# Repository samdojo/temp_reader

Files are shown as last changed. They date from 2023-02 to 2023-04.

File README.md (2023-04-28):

# Tempurature reader

This repo contains the schematic, code, and 3D print file to build a simple temperature reader

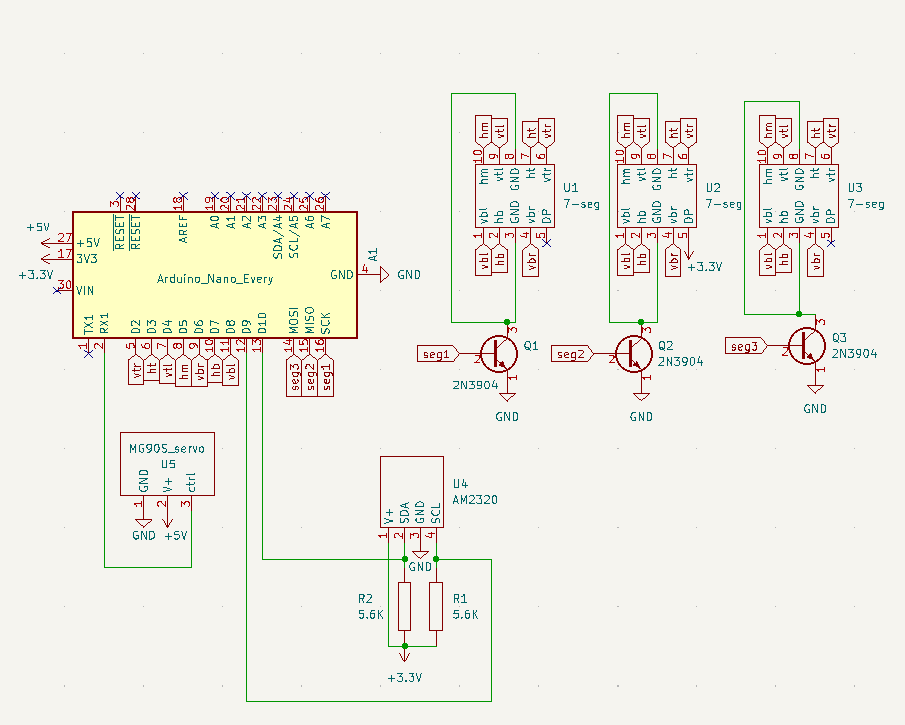
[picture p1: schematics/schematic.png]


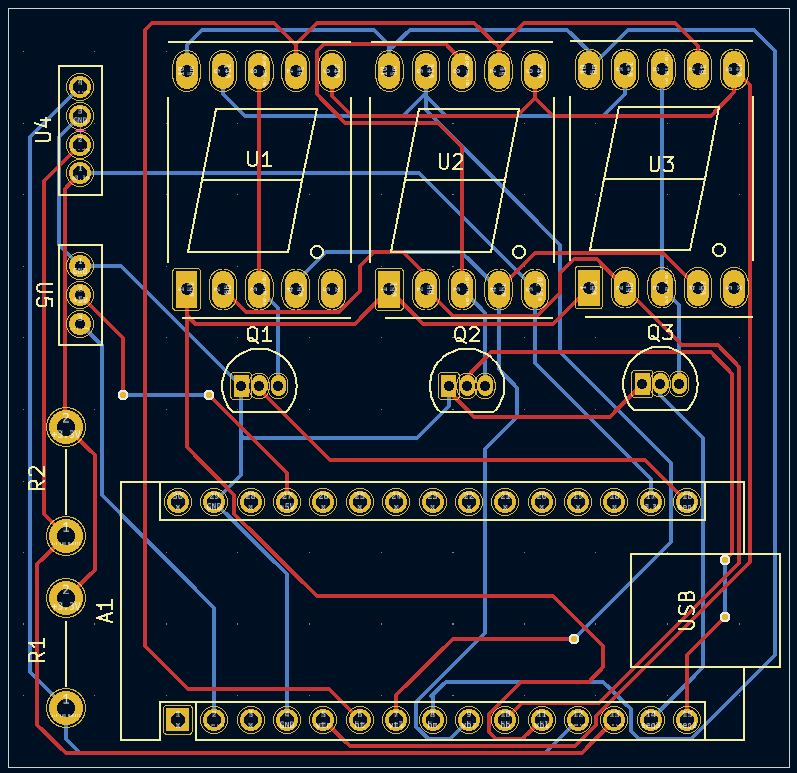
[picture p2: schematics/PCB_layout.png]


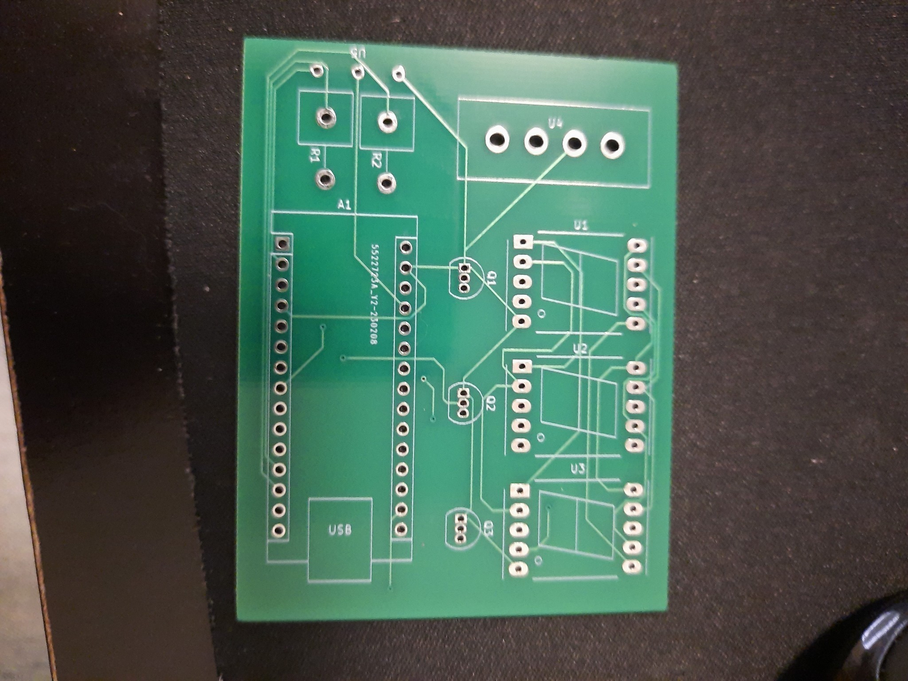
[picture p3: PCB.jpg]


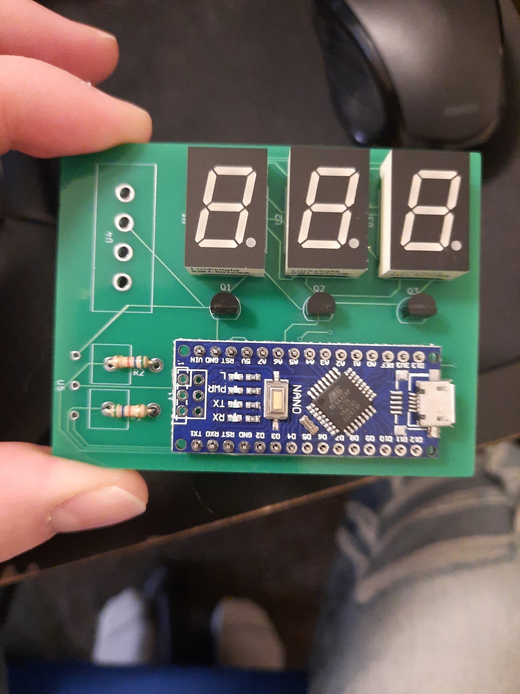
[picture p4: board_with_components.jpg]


#### Software Dependencies
- Arduino library "adafruit_AM2320" v1.2.1

#### Materials List
- Arduino Nano
- 3 single-digit seven-segment displays (KW1-501CSB)
- Tempurature and humidity sensor (AM2320)
- 3 NPN Transistors (2N3904)
- 2 pull-up resistors (2.2-10KOhm)
- Servo (SG90)
- 4 female-to-female jumper wires
- 5 #2 1/4" screws
- glue

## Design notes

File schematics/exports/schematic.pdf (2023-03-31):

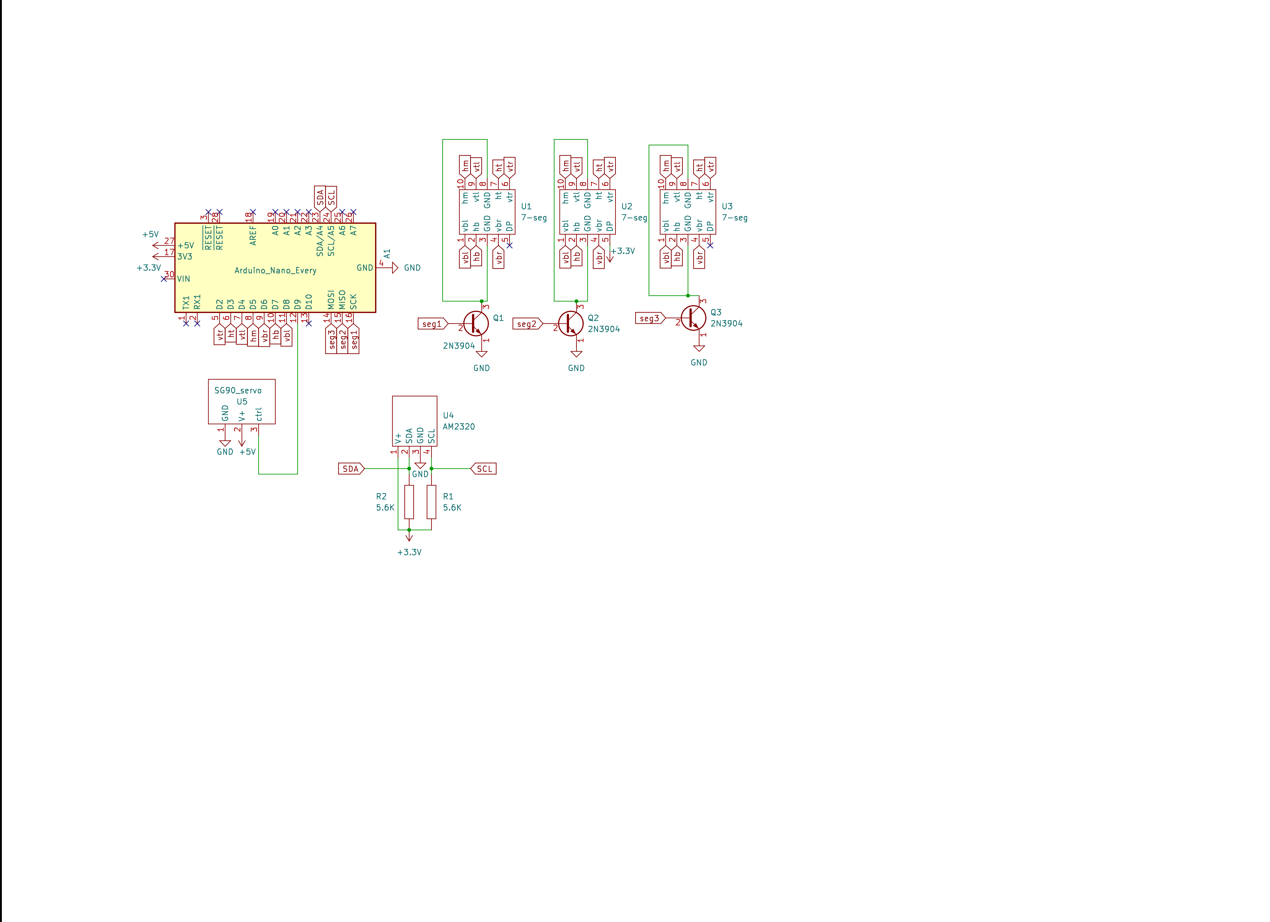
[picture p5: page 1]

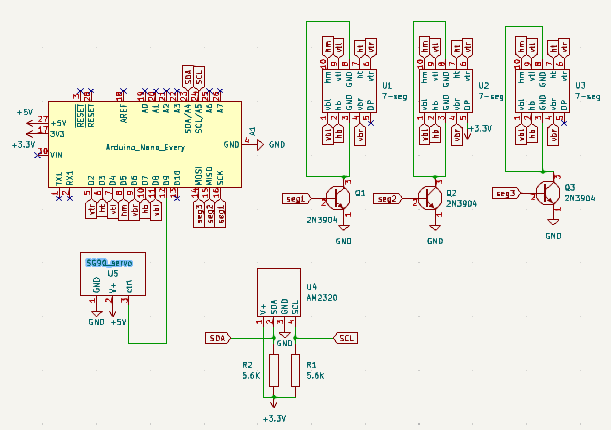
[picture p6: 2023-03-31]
schematics/exports/schematic.png

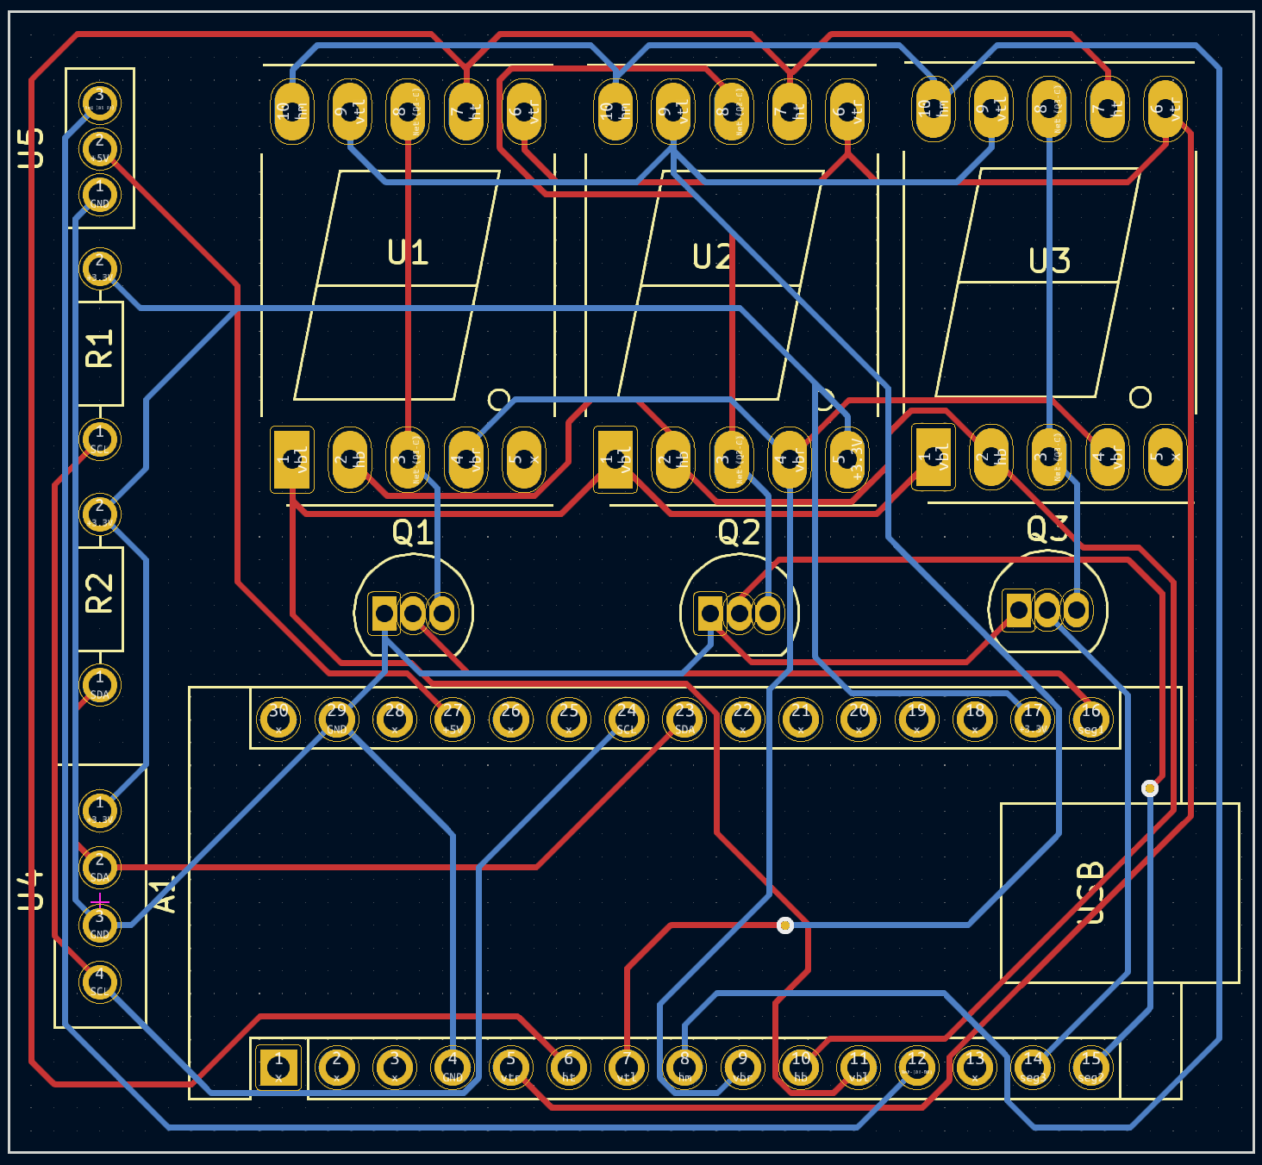
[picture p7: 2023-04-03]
schematics/exports/PCB_layout.png

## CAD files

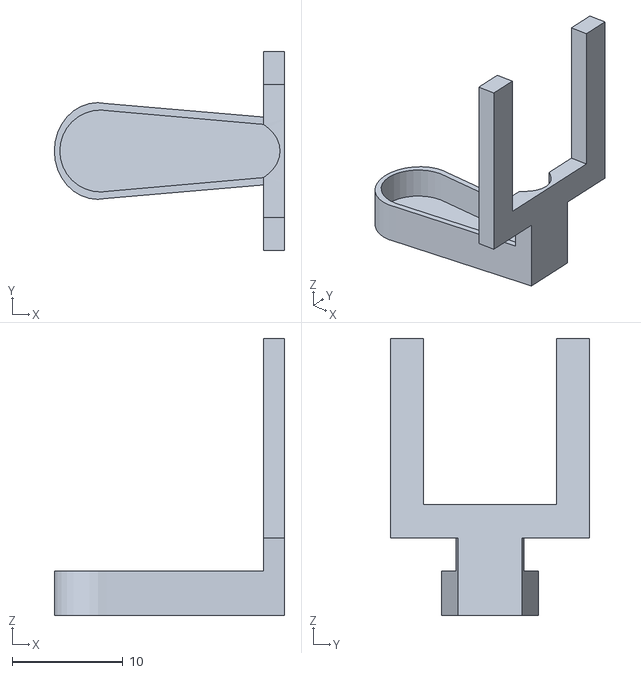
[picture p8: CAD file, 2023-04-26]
3DModels/arm.stl
20.8 x 18.0 x 25.0

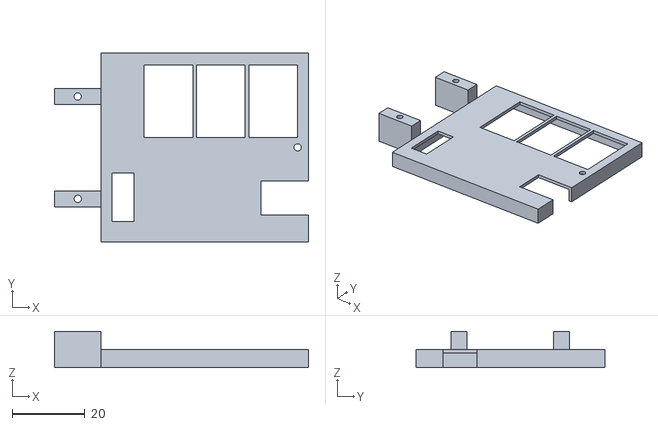
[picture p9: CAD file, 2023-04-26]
3DModels/lid.stl
69.8 x 52.0 x 9.93

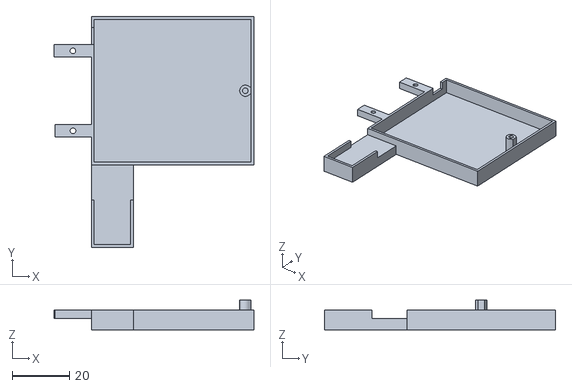
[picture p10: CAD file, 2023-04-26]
3DModels/case.stl
70.0 x 81.0 x 10.4

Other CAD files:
3DModels/arm.blend
3DModels/case.blend
3DModels/lid.blend

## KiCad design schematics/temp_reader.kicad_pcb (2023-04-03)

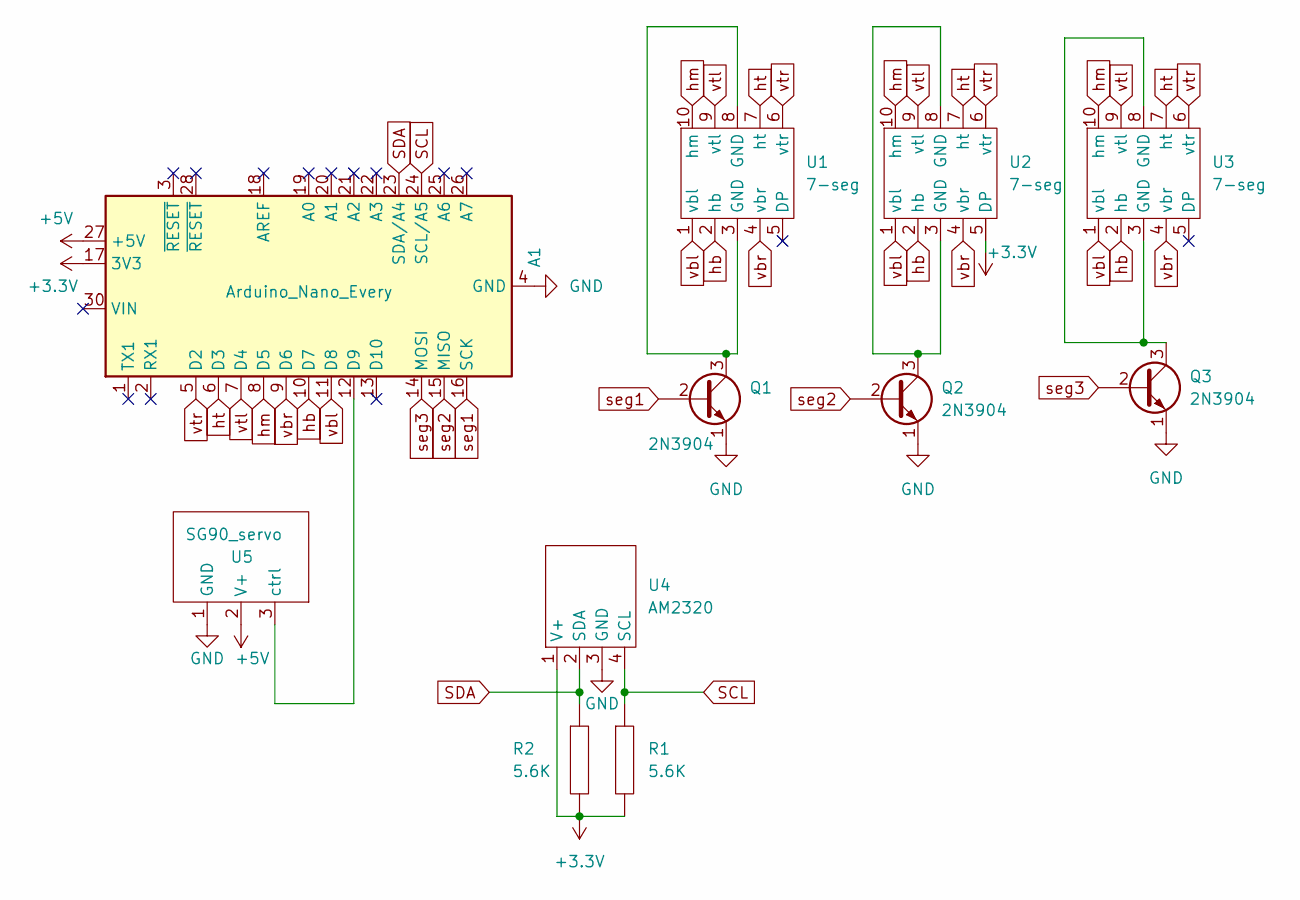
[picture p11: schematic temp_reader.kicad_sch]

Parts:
A1: Arduino_Nano_Every; Arduino_Nano
Q1, Q2, Q3: 2N3904; TO-92_Inline
R1, R2: 5.6K; resistor
U1, U2, U3: 7-seg; 7SegmentLED_LTS6760_LTS6780
U4: AM2320; AM2320 (temperature and humidity sensor)
U5: SG90_servo; MG90S servo

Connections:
+3.3V: A1.17 (3V3), R1.2, R2.2, U2.5 (DP), U4.1 (V+)
+5V: A1.27 (+5V), U5.2 (V+)
GND: A1.4 (GND), A1.29 (GND), Q1.1 (E), Q2.1 (E), Q3.1 (E), U4.3 (GND), U5.1 (GND)
unnamed: A1.12 (D9), U5.3 (ctrl)
unnamed: Q1.3 (C), U1.3 (GND), U1.8 (GND)
unnamed: Q2.3 (C), U2.3 (GND), U2.8 (GND)
unnamed: Q3.3 (C), U3.3 (GND), U3.8 (GND)
SCL: A1.24 (SCL/A5), R1.1, U4.4 (SCL)
SDA: A1.23 (SDA/A4), R2.1, U4.2 (SDA)
hb: A1.10 (D7), U1.2 (hb), U2.2 (hb), U3.2 (hb)
hm: A1.8 (D5), U1.10 (hm), U2.10 (hm), U3.10 (hm)
ht: A1.6 (D3), U1.7 (ht), U2.7 (ht), U3.7 (ht)
seg1: A1.16 (SCK), Q1.2 (B)
seg2: A1.15 (MISO), Q2.2 (B)
seg3: A1.14 (MOSI), Q3.2 (B)
vbl: A1.11 (D8), U1.1 (vbl), U2.1 (vbl), U3.1 (vbl)
vbr: A1.9 (D6), U1.4 (vbr), U2.4 (vbr), U3.4 (vbr)
vtl: A1.7 (D4), U1.9 (vtl), U2.9 (vtl), U3.9 (vtl)
vtr: A1.5 (D2), U1.6 (vtr), U2.6 (vtr), U3.6 (vtr)

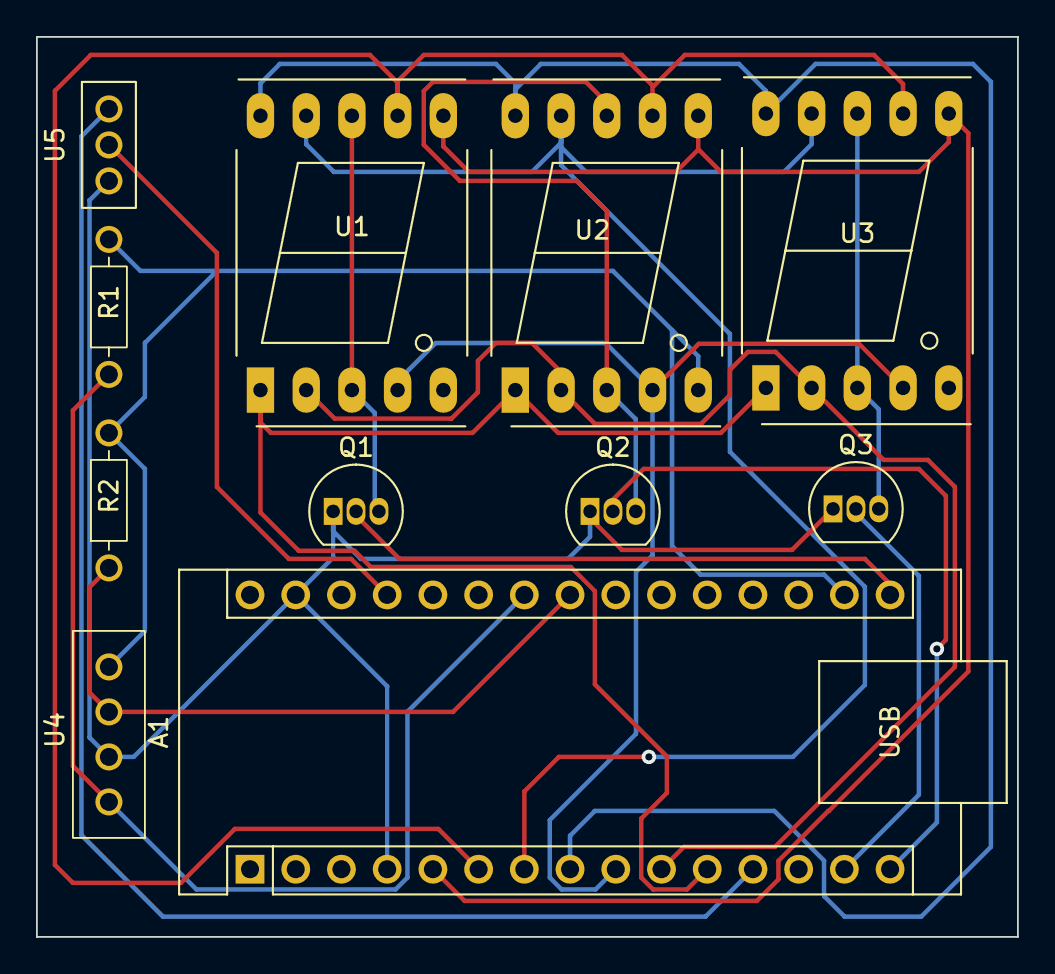
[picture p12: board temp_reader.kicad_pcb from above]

Board: 2 copper layers, 54.5 x 50.0 mm, 11 parts (0 on the bottom side), 19 nets.

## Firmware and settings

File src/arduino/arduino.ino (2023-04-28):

#include "display.h"
#include "Adafruit_Sensor.h"
#include "Adafruit_AM2320.h"
#include "arm.h"

Arm arm;
Adafruit_AM2320 tempSensor = Adafruit_AM2320();

int tempBy10;
int tick = 0;

void setup() {
  Serial.begin(9600);
  while (!Serial) {
    delay(10); // wait for serial port to open
  }
  Serial.println("starting...");

  Display::init();
  tempSensor.begin();
}

double inline celsius_to_farenheit(double celsius) {
  return (celsius * 1.8) + 32;
}

void loop() {
  if (tick > 99) {
    tick = 0;
    // round 100ths place and save 10ths place
    tempBy10 = (10.0 * celsius_to_farenheit(tempSensor.readTemperature()) + 0.5);
    Serial.print("Temp: ");
    Serial.println(float(tempBy10) / 10.0);

    if (tempBy10 < 740 && arm.isDown()) {
      arm.goUp();
    }
    else if (tempBy10 > 740 && !arm.isDown()) {
      arm.goDown();
    }
  }

  Display::print_digit(tempBy10 / 100, Display::Digit::DIGIT_10s);
  Display::print_digit((tempBy10 / 10) % 10, Display::Digit::DIGIT_1s);
  Display::print_digit(tempBy10 % 10, Display::Digit::DIGIT_10ths);

  tick++;
}

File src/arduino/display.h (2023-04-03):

struct Display {

  typedef enum Segment {
    SEG_VTR = 2, // vertical top-right
    SEG_HT = 3,  // horizontal top
    SEG_VTL = 4, // vertical top-left
    SEG_HM = 5,  // horizontal middle
    SEG_VBR = 6, // vertical bottom-right
    SEG_HB = 7,  // horizontal bottom
    SEG_VBL = 8  // vertical bottom-left
  };

  typedef enum Digit {
    DIGIT_10ths = 11,
    DIGIT_1s = 12,
    DIGIT_10s = 13
  };

  static void init() {
    pinMode(static_cast<int>(SEG_VTR), OUTPUT);
    pinMode(static_cast<int>(SEG_HT), OUTPUT);
    pinMode(static_cast<int>(SEG_VTL), OUTPUT);
    pinMode(static_cast<int>(SEG_HM), OUTPUT);
    pinMode(static_cast<int>(SEG_VBR), OUTPUT);
    pinMode(static_cast<int>(SEG_HB), OUTPUT);
    pinMode(static_cast<int>(SEG_VBL), OUTPUT);

    pinMode(static_cast<int>(DIGIT_10s), OUTPUT);
    pinMode(static_cast<int>(DIGIT_1s), OUTPUT);
    pinMode(static_cast<int>(SEG_VBL), OUTPUT);
  }

  static void inline print_digit(uint8_t num, Digit digit) {
    switch (num) {
      case 0: print_0(digit); break;
      case 1: print_1(digit); break;
      case 2: print_2(digit); break;
      case 3: print_3(digit); break;
      case 4: print_4(digit); break;
      case 5: print_5(digit); break;
      case 6: print_6(digit); break;
      case 7: print_7(digit); break;
      case 8: print_8(digit); break;
      case 9: print_9(digit); break;
      default: print_error(digit); break;
    }
    delay(5);
  }

private:

  static void inline write_segment(Segment seg, bool on) {
    digitalWrite(static_cast<int>(seg), on ? HIGH : LOW);
  }

  static void inline enable_digit(Digit digit, bool on) {
    digitalWrite(static_cast<int>(digit), on ? HIGH : LOW);
  }

  static void inline print_0(Digit digit) {
    enable_digit(digit);

    write_segment(SEG_VTR, true);
    write_segment(SEG_HT, true);
    write_segment(SEG_VTL, true);
    write_segment(SEG_HM, false);
    write_segment(SEG_VBR, true);
    write_segment(SEG_HB, true);
    write_segment(SEG_VBL, true);
  }

  static void inline print_1(Digit digit) {
    enable_digit(digit);

    write_segment(SEG_VTR, true);
    write_segment(SEG_HT, false);
    write_segment(SEG_VTL, false);
    write_segment(SEG_HM, false);
    write_segment(SEG_VBR, true);
    write_segment(SEG_HB, false);
    write_segment(SEG_VBL, false);
  }

  static void inline print_2(Digit digit) {
    enable_digit(digit);

    write_segment(SEG_VTR, true);
    write_segment(SEG_HT, true);
    write_segment(SEG_VTL, false);
    write_segment(SEG_HM, true);
    write_segment(SEG_VBR, false);
    write_segment(SEG_HB, true);
    write_segment(SEG_VBL, true);
  }

  static void inline print_3(Digit digit) {
    enable_digit(digit);
    
    write_segment(SEG_VTR, true);
    write_segment(SEG_HT, true);
    write_segment(SEG_VTL, false);
    write_segment(SEG_HM, true);
    write_segment(SEG_VBR, true);
    write_segment(SEG_HB, true);
    write_segment(SEG_VBL, false);
  }

  static void inline print_4(Digit digit) {
    enable_digit(digit);

    write_segment(SEG_VTR, true);
    write_segment(SEG_HT, false);
    write_segment(SEG_VTL, true);
    write_segment(SEG_HM, true);
    write_segment(SEG_VBR, true);
    write_segment(SEG_HB, false);
    write_segment(SEG_VBL, false);
  }

  static void inline print_5(Digit digit) {
    enable_digit(digit);
    
    write_segment(SEG_VTR, false);
    write_segment(SEG_HT, true);
    write_segment(SEG_VTL, true);
    write_segment(SEG_HM, true);
    write_segment(SEG_VBR, true);
    write_segment(SEG_HB, true);
    write_segment(SEG_VBL, false);
  }

  static void inline print_6(Digit digit) {
    enable_digit(digit);

    write_segment(SEG_VTR, false);
    write_segment(SEG_HT, true);
    write_segment(SEG_VTL, true);
    write_segment(SEG_HM, true);
    write_segment(SEG_VBR, true);
    write_segment(SEG_HB, true);
    write_segment(SEG_VBL, true);
  }

  static void inline print_7(Digit digit) {
    enable_digit(digit);

    write_segment(SEG_VTR, true);
    write_segment(SEG_HT, true);
    write_segment(SEG_VTL, false);
    write_segment(SEG_HM, false);
    write_segment(SEG_VBR, true);
    write_segment(SEG_HB, false);
    write_segment(SEG_VBL, false);
  }

  static void inline print_8(Digit digit) {
    enable_digit(digit);
    
    write_segment(SEG_VTR, true);
    write_segment(SEG_HT, true);
    write_segment(SEG_VTL, true);
    write_segment(SEG_HM, true);
    write_segment(SEG_VBR, true);
    write_segment(SEG_HB, true);
    write_segment(SEG_VBL, true);
  }

  static void inline print_9(Digit digit) {
    enable_digit(digit);

    write_segment(SEG_VTR, true);
    write_segment(SEG_HT, true);
    write_segment(SEG_VTL, true);
    write_segment(SEG_HM, true);
    write_segment(SEG_VBR, true);
    write_segment(SEG_HB, false);
    write_segment(SEG_VBL, false);
  }

  static void inline print_error(Digit digit) {
    enable_digit(digit);

    write_segment(SEG_VTR, false);
    write_segment(SEG_HT, true);
    write_segment(SEG_VTL, true);
    write_segment(SEG_HM, true);
    write_segment(SEG_VBR, false);
    write_segment(SEG_HB, true);
    write_segment(SEG_VBL, true);
  }

  static void inline enable_digit(Digit digit) {
    enable_digit(DIGIT_10s, false);
    enable_digit(DIGIT_1s, false);
    enable_digit(DIGIT_10ths, false); 

    enable_digit(digit, true);
  }

};

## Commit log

2023-02-26 added schematic picture
2023-02-26 added PCB layout picture
2023-02-26 added images of board
2023-03-18 updated PCB schematic and layout
    [temp_changer.kicad_pcb, temp_changer.kicad_sch, temp_reader.kicad_pcb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]
2023-03-18 renamed export files
    [temp_reader-B_Cu.gbr, temp_reader-B_Mask.gbr, temp_reader-B_Silkscreen.gbr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]
2023-03-20 added tempurature module
    [temp_reader-B_Cu.gbr, temp_reader-B_Mask.gbr, temp_reader-B_Silkscreen.gbr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]
2023-03-20 using 3.3v for decimal LED
    [temp_reader-B_Cu.gbr, temp_reader-B_Mask.gbr, temp_reader-B_Silkscreen.gbr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]
2023-03-31 updated servo model and adjusted temp sensor blueprint
    [temp_reader.kicad_pcb, temp_reader.kicad_sch]
2023-04-03 reorganized PCB layout to move sensor farther away from displays
    [temp_reader-B_Cu.gbr, temp_reader-B_Mask.gbr, temp_reader-B_Silkscreen.gbr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]
2023-04-03 added servo test code and fixed display bug
    [arduino.ino, display.h]
2023-04-03 added 3D files
    [case.blend, case.stl, lid.blend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]
2023-04-03 added materials list
2023-04-26 updated case and lid 3D models, added arm 3D model, removed test code
    [arm.blend, arm.stl, case.blend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]
2023-04-28 added materials
2023-04-28 added arm class; removed cool mode
